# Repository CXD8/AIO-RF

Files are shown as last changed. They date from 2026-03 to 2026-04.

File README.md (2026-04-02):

# RF Multifunction Device

An all-in-one RF platform built around the **ESP32-WROOM-32U**, combining Wi-Fi, Bluetooth, and sub-GHz RF into a single battery-powered device with a 2.8" LCD display and USB Type-C charging.

## Disclaimer
- **This project is intended for educational and research purposes only**
- **The author accepts no liability for regulatory non-compliance resulting from use of this project**
- **Users are solely responsible for ensuring compliance with all applicable local laws and regulations**
This project is provided **as-is, with absolutely no warranty of any kind**, express or implied. The author(s) accept **zero responsibility or liability** for any outcome resulting from the use, assembly, or operation of this hardware - including but not limited to property damage, fire, personal injury, or death.

**Use entirely at your own risk. The author(s) have no responsibility whatsoever for anything that goes wrong.**
- **Regulatory Disclaimer**
This project may use uncertified radio frequency (RF) modules. These components have not been independently tested or certified for compliance such as for FCC (USA), CE (EU), or any other regulatory framework.
ard.** This device may use a Protected LiPo/Li-ion battery with a BMS. LiPo/Li-ion batteries can swell, leak, catch fire, or explode if incorrectly charged, stored, handled, or if the hardware malfunctions. The author(s) accept no responsibility for any damage, injury, or death caused by battery failure or misuse.
- **RF transmission.** This device transmits RF signals. It is your sole responsibility to comply with all applicable local, national, and international radio frequency regulations (e.g. FCC, CE, OFCOM). Only operate in a controlled environment where RF emissions can be properly managed.
- **No certification.** This design has not been tested, certified, or approved for any commercial, consumer, safety-critical, or regulatory-controlled application.
- **No guarantees.** The author(s) make no guarantees regarding the accuracy or fitness for purpose of the schematic, BOM, firmware, or any associated documentation.

**By using, building, or operating this project in any form, you accept full and sole responsibility for all risks and any consequences that arise.**

By using this project in any form, you agree to assume all associated risks and responsibilities.

## How to Use
Connect via USB Type-C to flash firmware via your preferred flashing software through the onboard FT232RL(typically driver-free). You can also choose to flash directly through the exposed flashing pins and your own chosen flashing device. The MCP73871 handles battery charging automatically when USB is connected. Warning that the onboard battery controller does not have a cut-off threshold, a protected battery must be used. Refer to charging controller MCP73871-2CCI/ML for appropriate battery specifications.
The charging IC does not have low voltage cut-off. You must use an appropriate protected battery with a BMS. A battery is not required, it can be powered through USB-C.

## Why
RF development usually requires juggling multiple separate modules and boards. This consolidates everything into one clean, portable device for wireless experimentation and IoT development.

---
AIO-RF_transparent
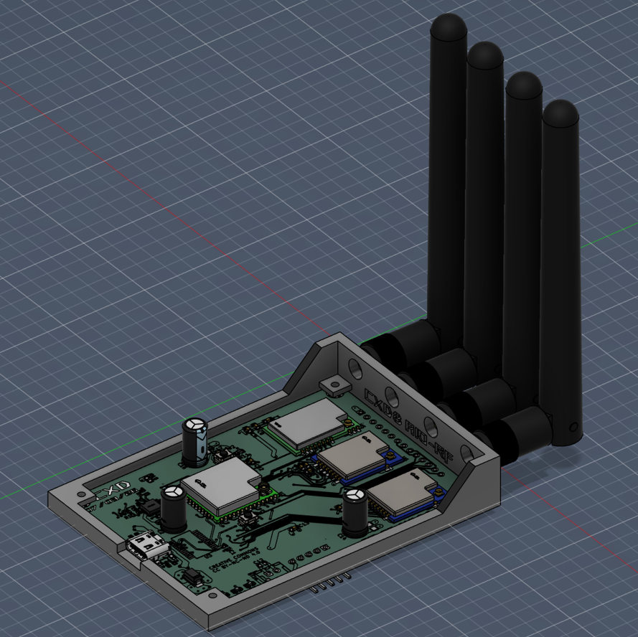
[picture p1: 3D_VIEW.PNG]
AIO-RF_transparent


## Bill of Materials

| # | References | Part | Package | Qty | LCSC |
|---|---|---|---|-----|---|
| 1 | C8, C9, C11, C19, C20, C21, C22 | CL10A226MP8NUNE | C0603 | 7 | [Link](https://www.lcsc.com/product-detail/C86295.html) |
| 2 | C1, C3, C6, C7, C17 | CL10B104KB8NNNC | C0603 | 5 | [Link](https://www.lcsc.com/product-detail/C1591.html) |
| 3 | C12, C13, C18 | CL10A475KO8NNNC | C0603 | 3 | [Link](https://www.lcsc.com/product-detail/C19666.html) |
| 4 | C4, C15 | CL21A106KAYNNNE | C0805 | 2 | [Link](https://www.lcsc.com/product-detail/C15850.html) |
| 5 | C5, C23 | CL10A106KP8NNNC | C0603 | 2 | [Link](https://www.lcsc.com/product-detail/C19702.html) |
| 6 | C14, C16 | OCR101M0JBK-0605 | CAP-TH_BD6.3-P2.50-D1.0-FD | 2 | [Link](https://www.lcsc.com/product-image/C134847.html) |
| 7 | C2 | SPZ1AM471E08000R | CAP-TH_BD6.3-P2.50-D1.0-FD | 1 | [Link](https://www.lcsc.com/product-detail/C122242.html) |
| 8 | R3, R10, R11, R13 | 0603WAF1002T5E | R0603 | 4 | [Link](https://www.lcsc.com/product-detail/C25804.html) |
| 9 | R5, R6, R7 | QR0603F470RP05 | R0603 | 3 | [Link](https://www.lcsc.com/product-detail/C176130.html) |
| 10 | R2, R8 | RC0603FR-0710KL | R0603 | 2 | [Link](https://www.lcsc.com/product-detail/C98220.html) |
| 11 | R9, R12 | 0603WAF5101T5E | R0603 | 2 | [Link](https://www.lcsc.com/product-detail/C23186.html) |
| 12 | R1 | 0603WAF2001T5E | R0603 | 1 | [Link](https://www.lcsc.com/product-detail/C22975.html) |
| 13 | D1 | SMAJ5.0A-C83329 | SMA_L4.3-W2.6-LS5.2-RD | 1 | [Link](https://www.lcsc.com/product-detail/C83329.html) |
| 14 | U1, U9 | AP2114H-3.3TRG1 | SOT-223_L6.7-W3.5-P2.30-BR | 2 | [Link](https://www.lcsc.com/product-image/C150716.html) |
| 15 | U6, U7 | E01-ML01SP4 | WIRELM-TH_E01-ML01SP4 | 2 | [Link](https://www.lcsc.com/product-detail/C97340.html) |
| 16 | U2 | ESP32-WROOM-32U(E) | ESP32-WROOM-32U | 1 | [Link](https://www.lcsc.com/product-detail/C701346.html) |
| 17 | U3 | FT232RL | SSOP-28_5.3x10.2mm_P0.65mm | 1 | [Link](https://www.lcsc.com/product-detail/C8690.html) |
| 18 | U5 | E07-400M10S | COMM-SMD_E07-400M10S | 1 | [Link](https://www.lcsc.com/product-detail/C2965513.html) |
| 19 | U8 | MCP73871-2CCI/ML | QFN-20_L4.0-W4.0-P0.50-BL-EP2.7 | 1 | [Link](https://www.lcsc.com/product-detail/C5121473.html) or [Link](https://www.aliexpress.com/item/1005009931582723.html) |
| 20 | SW2, SW3 | TS-1088-AR02016 | SW-SMD_L3.9-W3.0-P4.45 | 2 | [Link](https://www.lcsc.com/product-detail/C720477.html) |
| 21 | LED1, LED2, LED3 | HL-PST-1608H233W(9000-16000K) | LED0603-RD | 3 | [Link](https://www.lcsc.com/product-detail/C219226.html) |
| 22 | BT1 | Battery_Cell | JST_XH_B2B-XH-AM_1x02_P2.50mm_Vertical | 1 | [Link](https://www.lcsc.com/product-detail/C158014.html) |
| 23 | H1 | PZ254R-11-05P | HDR-TH_5P-P2.54-H-M-W10.4 | 1 | [Link](https://www.lcsc.com/product-detail/C492413.html) |
| 24 | LCD1 | HS280S010B | LCD-TH_HS280S010B | 1 | [Link](https://www.aliexpress.com/item/32795636902.html) |
| 25 | USB1 | TYPE-C 16P QTWT | USB-TYPE-C-SMD_TYPE-C-16P-QTWT | 1 | [Link](https://www.lcsc.com/product-detail/C5187472.html) |
| 26 | - | 18650 PROTECTED | - | 1 | [Link](https://www.aliexpress.com/item/32855314823.html) |
| 27 | - | JST MALE CONN (NOTE: NEED BOTH MALE AND FEMALE) | - | 1 | [Link](https://www.aliexpress.com/item/1005008783240077.html) |
| 28 | - | 18AWG WIRE | - | 1 | [Link](https://www.aliexpress.com/item/1005008563402600.html?) |
| 29 | - | IPEX/U.FL to SMA | - | 4 | [Link](https://www.aliexpress.com/item/1005009812335103.html) |
| 30 | - | SMA ANTENNA 2.4GHz | - | 3 | [Link](https://www.aliexpress.com/item/1005005535644339.html) |
| 31 | - | SMA ANTENNA 433MHz | - | 1 | [Link](https://www.aliexpress.com/item/1005009463421918.html) |

## Changelog - Images/3D models may not be up to date
- **08/03/2026** - Sample firmware released
- **08/03/2026** - Traces ran over/under NPTH. This is fixed

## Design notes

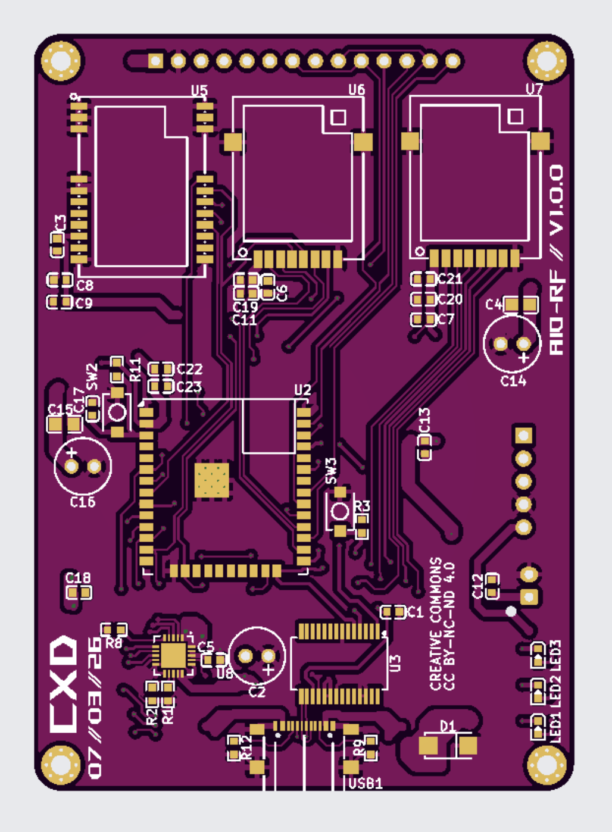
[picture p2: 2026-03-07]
Images/AIO-RF_2D_VIEW.png

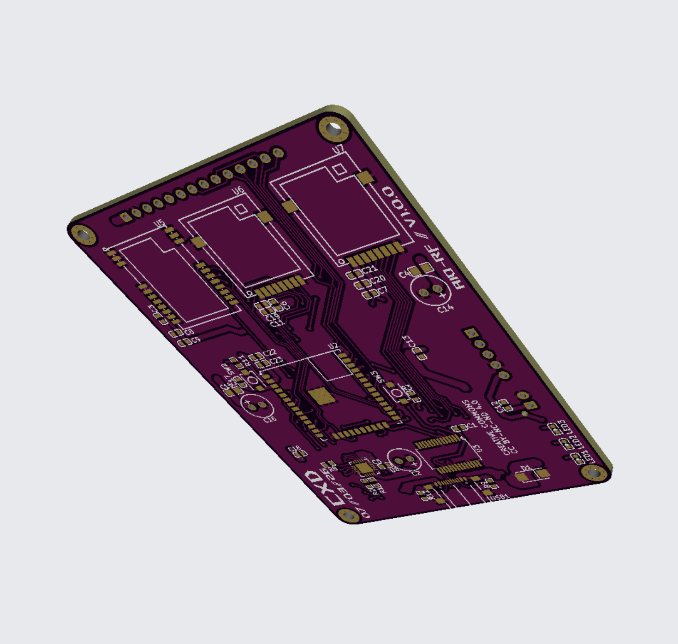
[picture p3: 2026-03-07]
Images/AIO-RF_3D_VIEW.png

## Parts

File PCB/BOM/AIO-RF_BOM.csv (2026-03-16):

# | References | Part | Package | Qty | LCSC
1 | C8, C9, C11, C19, C20, C21, C22 | CL10A226MP8NUNE | C0603 | 7 | https://www.lcsc.com/product-detail/C86295.html
2 | C1, C3, C6, C7, C17 | CL10B104KB8NNNC | C0603 | 5 | https://www.lcsc.com/product-detail/C1591.html
3 | C12, C13, C18 | CL10A475KO8NNNC | C0603 | 3 | https://www.lcsc.com/product-detail/C19666.html
4 | C4, C15 | CL21A106KAYNNNE | C0805 | 2 | https://www.lcsc.com/product-detail/C15850.html
5 | C5, C23 | CL10A106KP8NNNC | C0603 | 2 | https://www.lcsc.com/product-detail/C19702.html
6 | C14, C16 | OCR101M0JBK-0605 | CAP-TH_BD6.3-P2.50-D1.0-FD | 2 | https://www.lcsc.com/product-image/C134847.html
7 | C2 | SPZ1AM471E08000R | CAP-TH_BD6.3-P2.50-D1.0-FD | 1 | https://www.lcsc.com/product-detail/C122242.html
8 | R3, R10, R11, R13 | 0603WAF1002T5E | R0603 | 4 | https://www.lcsc.com/product-detail/C25804.html
9 | R5, R6, R7 | QR0603F470RP05 | R0603 | 3 | https://www.lcsc.com/product-detail/C176130.html
10 | R2, R8 | RC0603FR-0710KL | R0603 | 2 | https://www.lcsc.com/product-detail/C98220.html
11 | R9, R12 | 0603WAF5101T5E | R0603 | 2 | https://www.lcsc.com/product-detail/C23186.html
12 | R1 | 0603WAF2001T5E | R0603 | 1 | https://www.lcsc.com/product-detail/C22975.html
13 | D1 | SMAJ5.0A-C83329 | SMA_L4.3-W2.6-LS5.2-RD | 1 | https://www.lcsc.com/product-detail/C83329.html
14 | U1, U9 | AP2114H-3.3TRG1 | SOT-223_L6.7-W3.5-P2.30-BR | 2 | https://www.lcsc.com/product-image/C150716.html
15 | U6, U7 | E01-ML01SP4 | WIRELM-TH_E01-ML01SP4 | 2 | https://www.lcsc.com/product-detail/C97340.html
16 | U2 | ESP32-WROOM-32U(E) | ESP32-WROOM-32U | 1 | https://www.lcsc.com/product-detail/C701346.html
17 | U3 | FT232RL | SSOP-28_5.3x10.2mm_P0.65mm | 1 | https://www.lcsc.com/product-detail/C8690.html
18 | U5 | E07-400M10S | COMM-SMD_E07-400M10S | 1 | https://www.lcsc.com/product-detail/C2965513.html
19 | U8 | MCP73871-2CCI/ML | QFN-20_L4.0-W4.0-P0.50-BL-EP2.7 | 1 | https://www.lcsc.com/product-detail/C5121473.html or https://www.aliexpress.com/item/1005009931582723.html
20 | SW2, SW3 | TS-1088-AR02016 | SW-SMD_L3.9-W3.0-P4.45 | 2 | https://www.lcsc.com/product-detail/C720477.html
21 | LED1, LED2, LED3 | HL-PST-1608H233W(9000-16000K) | LED0603-RD | 3 | https://www.lcsc.com/product-detail/C219226.html
22 | BT1 | Battery_Cell | JST_XH_B2B-XH-AM_1x02_P2.50mm_Vertical | 1 | https://www.lcsc.com/product-detail/C158014.html
23 | H1 | PZ254R-11-05P | HDR-TH_5P-P2.54-H-M-W10.4 | 1 | https://www.lcsc.com/product-detail/C492413.html
24 | LCD1 | HS280S010B | LCD-TH_HS280S010B | 1 | https://www.aliexpress.com/item/32795636902.html
25 | USB1 | TYPE-C 16P QTWT | USB-TYPE-C-SMD_TYPE-C-16P-QTWT | 1 | https://www.lcsc.com/product-detail/C5187472.html
26 | - | 18650 PROTECTED | - | 1 | https://www.aliexpress.com/item/32855314823.html
27 | - | JST MALE CONN | - | 1 | https://www.aliexpress.com/item/1005008783240077.html
28 | - | 18AWG WIRE | - | 1 | https://www.aliexpress.com/item/1005008563402600.html
29 | - | IPEX/U.FL to SMA | - | 4 | https://www.aliexpress.com/item/1005009812335103.html
30 | - | SMA ANTENNA 2.4GHz | - | 3 | https://www.aliexpress.com/item/1005005535644339.html
31 | - | SMA ANTENNA 433MHz | - | 1 | https://www.aliexpress.com/item/1005009463421918.html

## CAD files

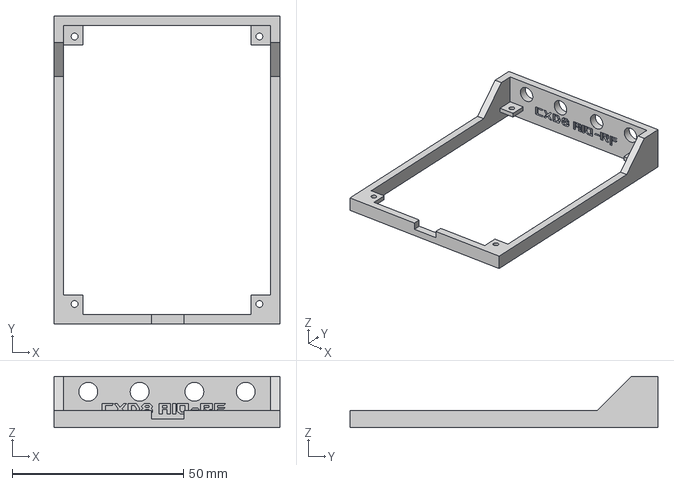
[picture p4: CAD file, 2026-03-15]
3D_Models/AIO-RF_3D_HOUSING.step
66.0 x 90.0 x 15.0 mm

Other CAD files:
3D_Models/AIO-RF_Case_release.f3z

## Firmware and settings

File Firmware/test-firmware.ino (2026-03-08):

#include <SPI.h>
#include <TFT_eSPI.h>
#include <RF24.h>
#include <RadioLib.h>

// ==========================================
// PIN DEFINITIONS
// ==========================================
// RF Shared SPI Bus (HSPI)
#define RF_SCK    14
#define RF_MOSI   13
#define RF_MISO   27

// U6: nRF24L01+ Module #1
#define NRF1_CE   17
#define NRF1_CSN  4

// U7: nRF24L01+ Module #2
#define NRF2_CE   25
#define NRF2_CSN  26

// U5: CC1101 Module
#define CC_CSN    33
#define CC_GDO0   32
// ==========================================

// Initialize Objects
TFT_eSPI tft = TFT_eSPI(); 
RF24 nrf1(NRF1_CE, NRF1_CSN);
RF24 nrf2(NRF2_CE, NRF2_CSN);
CC1101 cc = new Module(CC_CSN, CC_GDO0, RADIOLIB_NC);

void setup() {
  Serial.begin(115200);
  delay(1000);

  // 1. Initialize Display First (Uses standard VSPI defined in User_Setup.h)
  tft.init();
  tft.setRotation(1); // Landscape
  tft.fillScreen(TFT_BLACK);
  tft.setTextColor(TFT_WHITE, TFT_BLACK);
  tft.setTextSize(2);
  
  tft.drawString("System Booting...", 10, 10);
  delay(1000);

  // 2. Re-route the global standard SPI object to your RF pins
  // SPI.begin(SCK, MISO, MOSI, SS);
  SPI.begin(RF_SCK, RF_MISO, RF_MOSI, -1);
  tft.drawString("RF SPI Bus Started", 10, 40);
  delay(500);

  // 3. Initialize U6 (nRF24 #1)
  tft.drawString("Checking nRF24 #1...", 10, 70);
  if (nrf1.begin()) {
    tft.setTextColor(TFT_GREEN, TFT_BLACK);
    tft.drawString("nRF24 #1: OK     ", 10, 70);
  } else {
    tft.setTextColor(TFT_RED, TFT_BLACK);
    tft.drawString("nRF24 #1: FAIL   ", 10, 70);
  }
  tft.setTextColor(TFT_WHITE, TFT_BLACK); // Reset color

  // 4. Initialize U7 (nRF24 #2)
  tft.drawString("Checking nRF24 #2...", 10, 100);
  if (nrf2.begin()) {
    tft.setTextColor(TFT_GREEN, TFT_BLACK);
    tft.drawString("nRF24 #2: OK     ", 10, 100);
  } else {
    tft.setTextColor(TFT_RED, TFT_BLACK);
    tft.drawString("nRF24 #2: FAIL   ", 10, 100);
  }
  tft.setTextColor(TFT_WHITE, TFT_BLACK);

  // 5. Initialize U5 (CC1101)
  tft.drawString("Checking CC1101...", 10, 130);
  int cc_state = cc.begin();
  if (cc_state == RADIOLIB_ERR_NONE) {
    tft.setTextColor(TFT_GREEN, TFT_BLACK);
    tft.drawString("CC1101: OK       ", 10, 130);
  } else {
    tft.setTextColor(TFT_RED, TFT_BLACK);
    tft.drawString("CC1101: FAIL (" + String(cc_state) + ")", 10, 130);
  }
  tft.setTextColor(TFT_WHITE, TFT_BLACK);

  // Finish setup
  tft.setTextColor(TFT_YELLOW, TFT_BLACK);
  tft.drawString("All Modules Checked!", 10, 170);
}

void loop() {
  // In your actual firmware, you would check for received packets here:
  // if(nrf1.available()) { ... }
  // if(nrf2.available()) { ... }
  // if(received_flag_cc1101) { ... }

  // Simple heartbeat to show the ESP32 is running
  static int counter = 0;
  tft.setTextColor(TFT_CYAN, TFT_BLACK);
  tft.drawString("Uptime: " + String(counter++) + " s ", 10, 210);
  delay(1000);
}
